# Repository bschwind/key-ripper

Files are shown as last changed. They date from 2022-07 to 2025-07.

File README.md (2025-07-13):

# key-ripper

A keyboard personalized for myself, designed in KiCad, with custom firmware written in Rust.

key-ripper
feet
macbook-keyboard
usb-c

The story behind this board can be found in [this reddit post](https://www.reddit.com/r/MechanicalKeyboards/comments/vtlujd/i_built_a_keyboard_pcb_and_wrote_firmware_for_it/).

I also gave a (time-constrained) talk on making this keyboard which you can view [here](https://www.youtube.com/watch?v=x7LQevYn7d0).
Sadly I didn't get to cover everything I wanted to talk about when it comes to embedded Rust, but I hope you find it entertaining.

## Main Features and Requirements

* Be cheap to manufacture (can easily be ordered and fabricated by JLCPCB, uses an RP2040)
* USB C Connector
* Have dedicated function keys
* Reduce friction changing between a macbook keyboard and this one
* Stay relatively compact
* Full sized arrow keys with a gap (on the left and right) for easily finding the up arrow without looking
* No right shift key (this allows for the arrow keys to sit below the Enter key, and I never use right shift)
* Support for screw-in stabilizers first and foremost, along with snap-in stabilizers, and plate-mounted stabilizers when using a top plate
* Can sit on top of a macbook keyboard
* Easy to assemble - order a PCB, press it into the 3D printed case, and use 4 optional screws if the fit isn't snug
* Firmware written in Rust, debuggable with knurling-rs

## Setup

* Order a PCB with the production files from the [latest release](https://github.com/bschwind/key-ripper/releases).
* When you receive the board, plug it in via USB C and follow [the instruction to flash the firmware](https://github.com/bschwind/key-ripper/blob/main/firmware/README.md).

## 3D Printed Case

The STEP files for the case are available in the [case directory](./case).

They were produced with Rust bindings to OpenCascade. You can find the code for the keyboard case [here](https://github.com/bschwind/opencascade-rs/blob/2eefc2c0322c1cb65bd3279fbedeba416aef8858/examples/src/keyboard_case.rs).

The case can be printed as two separate parts with a dovetail connection (use your slicer and cut up the parts for whatever suits your print bed size), or it can be printed as one full piece.

The PCB can then be slotted into the case with the top edge first (the edge with the USB connector), then press the bottom edge in to fit it into the case. It's usually a snug fit. You can then use 4 M2x4 flat head "laptop screws" to secure the PCB in the middle two holes on the top and bottom edges.

The case feet can be printed and pressed directly into the bottom of the case. The STEP files were printed on a Prusa MK4 and MK3S, both of which had successful tolerances for the press-fit of the case feet.

## Current Version (v0.3.1)

[v0.3.1 PCBWay Production Files](https://github.com/bschwind/key-ripper/releases/tag/v0.3.1)

Version v0.3.1 adds an ESD protector on the USB connector, and was kindly sponsored and manufactured by PCBWay.

pcbway-matte-black-rp2040

pcbway-matte-black-usb-c

## v0.3

[v0.3 JLCPCB Production Files](https://github.com/bschwind/key-ripper/releases/tag/v0.3)

Version 0.3 adds some iterative hardware improvements over v0.2:

* Added support for threaded inserts on the PCB
* Added pass-through holes for M2 hex spacers
* Better impedance matching on the USB lines
* Added a cross-hatch copper pour to reduce warping compared to a solid copper pour
* Added some test points on the board
* Moved many components to a 1608 metric size for easier soldering
* Added an optional TRRS connector footprint for connecting to a debug probe
* Switched to a much smaller QSPI flash chip
* Added fancier patterns on the top and bottom plates

## v0.2

[v0.2 JLCPCB Production Files](https://github.com/bschwind/key-ripper/releases/tag/v0.2)

Version 0.2 improves upon some of the issues in v0.1, with some intentional choices that could be seen as a downgrade:

* Added a copper pour on both sides for a flatter PCB
* Shifted a few components away from the screw-in stabilizer holes to avoid screw washers touching the components
* Fixed some silkscreens for the reset and USB boot buttons
* Fixed the alignment of the F5 key
* **Controversial** - Changed the switch footprint to normal MX soldered switches instead of Kailh hotswap footprints. This allows for simpler boards that don't require a top plate.

## Version v0.1

Version 0.1 _works_ but there are some issues:

* The PCB warps during SMT reflow because there is a copper pour on only one side
* The silkscreens are not labeled well (SW1, SW2, SW3, etc. instead of Q, W, E, R, etc.)
* The F5 key is slightly more to the left of the F6 key than it should be, which leads to incompatible top plates between v0.1 and v0.2

Version 0.1 uses Kailh hotswap sockets. Combined with the top plate, this is good for trying out different switches, but adds complexity
in the build process. It requires more parts, and I had to 3D print 3.4mm M2 spacers.

[v0.1 JLCPCB Production Files](https://github.com/bschwind/key-ripper/releases/tag/v0.1)

PCB Front
PCB Back

## Production Files

For every PCB fabrication order, I make a github release and upload the files I used to make the order.

You can see a list of releases [here](https://github.com/bschwind/key-ripper/releases).

## Create a Gerber File

For most PCB fabrication shops, they expect gerber files, which are essentially files that describe the layout of pads/traces/geometry for each layer in a PCB. They also contain the drill locations if your PCB has any holes. All these layers should be placed in a directory and compressed to a zip file for uploading.

To create a gerber zip in KiCAD:

* Open up PCBNEW (KiCAD's PCB design tool)
* Select `File` -> `Plot`
* Select the following layers:
    * F.Cu
    * B.Cu
    * F.Paste
    * B.Paste
    * F.SilkS
    * B.SilkS
    * F.Mask
    * B.Mask
    * Edge.Cuts
* Leave all the other settings to their defaults
* Output to a directory named `gerber` (this is just convention, any name will do)
* Click `Plot`
* Next click `Generate Drill Files` with an `Excellon` drill file format, and a `Gerber` map file format
* Make sure the `Drill Units` are in `Millimeters`
* Output to the same directory you did for the previous gerber layers
* Click `Generate Drill File`
* Zip the `gerber` directory into a `gerber.zip` file and it's ready to upload!

**Note**: Check the PCB vendor's website for special KiCAD instructions, as they sometimes prefer certain settings when exporting.

OSHPark can directly accept `*.kicad_pcb` files so you don't need to export gerbers when ordering there.

## Create a Bill of Materials (for JLCPCB)

From the schematic viewer:

* Click the "BOM" button in the upper right toolbar
* Use the `bom_csv_grouped_by_value_with_fp`
* The output file won't have a `.csv` extension, so add it

Modify the CSV file:
* Rename the following columns:
    * `Ref` -> `Designator`
    * `Qnty` -> `Quantity`
* Delete the following columns:
    * `Cmp name`
    * `Description`
    * `Vendor`
* Add the following column:
    * `LCSC Part #`
* Remove any part rows you don't need to populate
* For each part, look it up on `jlcpcb.com/parts` and copy over both the footprint and the LCSC part number into their respective columns

In general, try to use as many "basic parts" as you can from JLCPCB. Each "extended part" costs an extra 300 yen per board.

## Create the Position File (for JCLPCB's pick-and-place machines)

From KiCad's PCB design tool:

* `File` -> `Fabrication Outputs` -> `Footprint Position (.pos) File`
* `Format`: `CSV`
* `Units`: `Millimeters`
* `Files`: `Single file for board`
* `Include footprints with SMD pads even if not marked Surface Mount`: `checked`
* Click `Generate Position File`

Modify the CSV file:

* Rename the following columns:
    * `Ref` -> `Designator`
    * `Qnty` -> `Quantity`
    * `Val` -> `Value`
    * `PosX` -> `Mid X`
    * `PosY` -> `Mid Y`
    * `Rot` -> `Rotation`
    * `Side` -> `Layer`

When uploading to JLCPCB, you may need to modify the rotation values. It will show you red dots on pin 1 for the relevant components, as well as a red `+` for components with polarity, so double check against your silkscreen and placement. Positive rotation goes counter-clockwise, so if you need to rotate a part counter-clockwise one turn, add 90 degrees. Subtract 90 to rotate one turn clockwise, and modulo 360 degrees to keep the overall rotation value positive.

## Firmware Debugging

Set the `DEFMT_LOG` environment variable.

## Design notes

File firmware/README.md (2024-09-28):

# key-ripper

## Dependencies

* [Rust Toolchain](https://rustup.rs/)

```
rustup target add thumbv6m-none-eabi
cargo install elf2uf2-rs
```

## Flash Code

If you just got the PCB from a PCB manufacturer, chances are you can plug in the board directly via USB C and it will show up as a USB mass-storage device, ready for flashing.

If not, hold the "USB Boot" button (near the QSPI chip), and either press the reset button or re-insert the USB cable to put the board in USB mass-storage bootloader mode.

```
cargo run --release
```

### Troubleshooting

If you get an error such as:

```
Error: "Memory segment 0x010000->0x010094 is outside of valid address range for device"
```

Double check that your `RUSTFLAGS` environment variable, as it will take precedence over the values set in `./cargo/config.toml`.

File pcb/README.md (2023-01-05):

# Notes

* The RP2040 samples the QSPI_SS line on boot. If this line is low, it will boot into its USB bootloader mode (i.e. enumerate as a mass storage device so you can upload new firmware). If this line is high on boot, it will start reading program instructions from the quad-SPI flash chip.

## Layout Notes

Just some measurements I've written down for my own designs are:
standard MX cutout - 14×14mm
distance between switches (center to center) - 19.05mm (both vertically and horizontally)
distance between caps - 0.95mm
distance between cap and case side - 0.475mm

Calculation example (60% case):
width of a case: 6 + (19.05 * 15) + (0.475 * 2) = 3mm bezel on each side, gap between case side and caps on each side, 15 keys in row.

Edit: 19.05mm distance between switches are only correct if they are two 1u keys. So for something like a 1.5u and 1u key distance between their centers would be (19.05 * 1.5)mm.

## TRRS Debug Connector

The footprint for the debug connector is a 3.5mm TRRS jack (part number PJ-320A, LCSC part number C2884926).

This footprint should be equivalent to the MJ-4PP-9 connector which is more easily found in Japan.

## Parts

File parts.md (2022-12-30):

# Parts List

Use 0402 metric (1005 imperial) footprints for all capacitors and resistors where possible.

## JLCPCB Parts

1x RP2040
    Extended
    C2040
    https://datasheet.lcsc.com/lcsc/2201101600_Raspberry-Pi-RP2040_C2040.pdf

1x USB C Connector
    Extended
    C165948
    https://datasheet.lcsc.com/lcsc/2205251630_Korean-Hroparts-Elec-TYPE-C-31-M-12_C165948.pdf

1x 3.3V Voltage Regulator
    Basic
    XC6206P
    C5446
    https://datasheet.lcsc.com/szlcsc/Torex-Semicon-XC6206P332MR_C5446.pdf

1x Schottky Diode
    Basic
    5819W SOD-123
    C8598
    https://datasheet.lcsc.com/szlcsc/Changjiang-Electronics-Tech-CJ-B5819W_C8598.pdf

1x Ferrite Bead
    Basic
    Sunlord GZ2012D101TF
    C1015
    https://datasheet.lcsc.com/szlcsc/Sunlord-GZ2012D101TF_C1015.pdf

1x Resettable Fuse
    Extended
    TLC-PSMD050
    C261942
    https://datasheet.lcsc.com/szlcsc/TLC-Electronic-TLC-PSMD050_C261942.pdf

1x Green LED
    Basic
    0805 Light Emitting Diodes (LED) ROHS
    C2297

1x Crystal Resonator (12MHz, 20pF load)
    Basic
    X322512MSB4SI
    C9002
    https://datasheet.lcsc.com/lcsc/2103291203_Yangxing-Tech-X322512MSB4SI_C9002.pdf

1x 16MB QSPI Flash
    Basic
    W25Q128JVSIQ
    C97521
    https://datasheet.lcsc.com/lcsc/1811142111_Winbond-Elec-W25Q128JVSIQ_C97521.pdf

Nx Kailh Hotswap Sockets
    Extended
    CPG151101S11
    C2803348
    https://jlcpcb.com/parts/componentSearch?isSearch=true&searchTxt=CPG151101S11

Nx Diodes
    Basic
    1N4148W
    C81598
    SOD-123
    https://datasheet.lcsc.com/lcsc/1811061725_ST-Semtech-1N4148W_C81598.pdf

2x tactile switch
    Basic
    TS-1187A-B-A-B
    C318884
    https://datasheet.lcsc.com/lcsc/2002271431_XKB-Connectivity-TS-1187A-B-A-B_C318884.pdf

1 uF C
    Basic
    0402 footprint
    50V 1uF X7R ±10% 0805  Multilayer Ceramic Capacitors MLCC - SMD/SMT ROHS
    C52923

0.1uF (100nF) C
    Basic
    50V 100nF X7R ±10% 0402  Multilayer Ceramic Capacitors MLCC - SMD/SMT ROHS
    C307331

30 pF C
    Basic
    50V 30pF C0G ±5% 0402  Multilayer Ceramic Capacitors MLCC - SMD/SMT ROHS
    C1570

27 ohm R
    Basic
    1/10W Thick Film Resistors 75V ±1% ±200ppm/℃ -55℃~+155℃ 27Ω 0603  Chip Resistor - Surface Mount ROHS
    C25190

1k ohm R
    Basic
    1/16W Thick Film Resistors 50V ±1% ±100ppm/℃ -55℃~+155℃ 5.1kΩ 0402  Chip Resistor - Surface Mount ROHS
    C11702

10k ohm R
    Basic
    1/16W Thick Film Resistors 50V ±1% ±100ppm/℃ -55℃~+155℃ 10kΩ 0402  Chip Resistor - Surface Mount ROHS
    C25744

5.1k ohm R
    Basic
    1/16W Thick Film Resistors 50V ±1% ±100ppm/℃ -55℃~+155℃ 5.1kΩ 0402  Chip Resistor - Surface Mount ROHS
    C25905

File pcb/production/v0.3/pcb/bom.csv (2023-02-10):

Comment | Designator | Footprint | LCSC
2.2uF | C1,C2,C19 | 0603 | C23630
100nF | C3,C8,C9,C10,C11,C12,C13,C14,C15,C16,C17,C18 | 0402 | C307331
1uF | C4,C5 | 0402 | C52923
30pF | C6,C7 | 0603 | C1658
D_Small | D1,D2,D3,D4,D5,D6,D7,D8,D9,D10,D11,D12,D13,D14,D15,D16,D17,D18,D19,D20,D21,D22,D23,D24,D25,D26,D27,D28,D29,D30,D31,D32,D33,D34,D35,D36,D37,D38,D39,D40,D41,D42,D43,D44,D45,D46,D47,D48,D49,D50,D51,D52,D53,D54,D55,D56,D57,D58,D59,D60,D61,D62,D63,D64,D65,D66,D67,D68,D69,D70,D71,D72,D73,D74,D75 | SOD-123 | C81598
5819W | D76,D78 | SOD-123 | C8598
Power LED (Green) | D77 | 0805 | C2297
TLC_PSMD050 | F1 | 0805 | C261942
100@100MHz | FB1 | 0805 | C1015
27 ohm | R1,R2 | 0603 | C25190
1k ohm | R3,R5,R9 | 0603 | C21190
10k ohm | R4,R8 | 0603 | C25804
5.1k | R6,R7 | 0603 | C23186
RP2040 | U1 | LQFN-56_EP_7.0x7.0x0.4P | C2040
TYPE-C-31-M-12 | U2 | TYPE-C-31_L8.94_W7.3 | C165948
XC6206PxxxMR | U3 | SOT-23-3L | C5446
W25Q16JVUXIQ | U4 | USON-8-EP(2x3) | C2843335
USB Boot | U5 | SMD-SW-4_5.1x5.1x1.5 | C318884
Reset | U6 | SMD-SW-4_5.1x5.1x1.5 | C318884
12MHz - 20pF | Y1 | SMD3225-4P | C9002

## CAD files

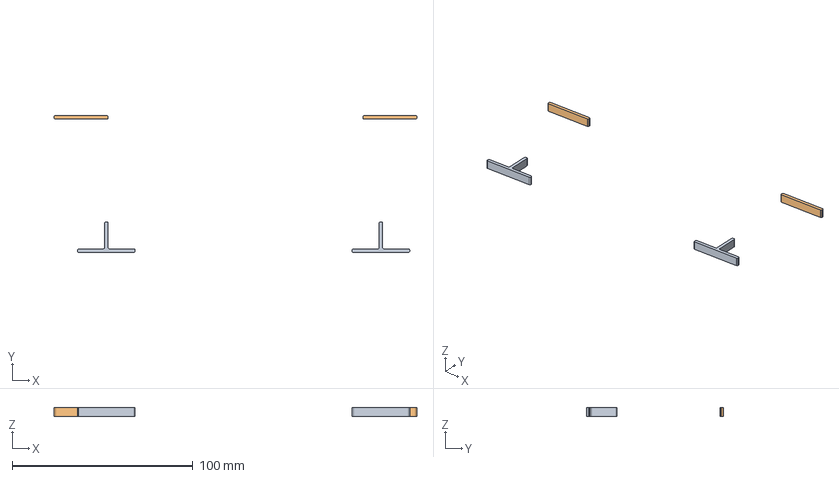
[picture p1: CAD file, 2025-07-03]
case/case_feet.step
201.1 x 75.8 x 5.00 mm

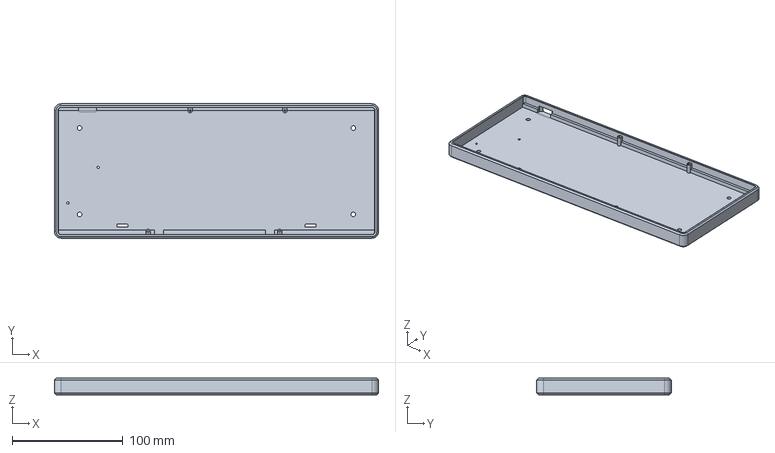
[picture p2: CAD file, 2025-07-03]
case/keyboard.step
293.1 x 121.7 x 15.1 mm

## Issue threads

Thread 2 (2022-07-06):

Add a ground pour to both sides

bschwind, 2022-07-06:
The PCB gets warped excessively during SMT reflow when the amount of copper on each side is unbalanced.

bschwind, 2022-07-10:
Fixed by d41e0e987a201cc1591b78f466c40796db80041b

Closed 2022-07-10.

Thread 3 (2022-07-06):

Fix silkscreen labels

bschwind, 2022-07-06:
At some point, the silkscreen labels for the keys and the push buttons got "reset" to their default kicad part labels (e.g. "SW1" or "U6").

bschwind, 2022-07-26:
Fixed by 72a85561d25322354060a1e48d76111535a5a0b2

The switch footprint square has been removed and the `SW**` number indicators have been moved under the switch.

Closed 2022-07-26.

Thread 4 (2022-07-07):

Screw-in stabilizer washers partially overlap some components

bschwind, 2022-07-07:
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

bschwind, 2022-07-10:
Fixed by 4a27d429b65c34ad5d87b87f041a81868366f658

Closed 2022-07-10.

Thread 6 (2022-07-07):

F5 key is spaced too far left of the F6 key

bschwind, 2022-07-07:
This was just a mistake in the PCB layout, oops!

bschwind, 2022-07-10:
Fixed by 811e14eb88a7b8bd4877243777f387e24d2578af

Closed 2022-07-10.

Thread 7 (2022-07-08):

Replace hard-wired power LED with a firmware-controlled LED

bschwind, 2022-07-08:
It's good to know power is working, but a firmware controlled LED can help with debugging and can be turned off when not in use. The current power LED is quite bright.

bschwind, 2022-07-10:
Fixed by 8c3728c21a9c1a877c4a96404b246dc875074b08

Closed 2022-07-10.

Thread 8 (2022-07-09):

Startup takes awhile when plugged in to a computer

bschwind, 2022-07-09:
It sometimes takes up to 10 seconds for the board to start acting as a keyboard after being plugged into a computer.

Not sure if I have some issues with the boot circuitry, which causes some ROM bootloader to timeout and then switch to QSPI booting, or if it's a software issue. Will need further debugging.

bschwind, 2022-07-09:
Increasing the `scan_countdown` timer to a longer value (in my case, I tried 80ms) seems to allow the keyboard to respond much faster when plugged in.

Closed 2022-07-09.

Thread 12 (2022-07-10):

Replace kailh hotswap socket footprint with standard MX footprint

bschwind, 2022-07-10:
The kailh hotswap sockets are kind of a pain, take up extra board space, and are incompatible with a design where you might want to solder the switches instead of plugging them in.

Instead, a standard MX footprint should be used, and then MillMax 3305-X sockets can be installed:

https://www.mill-max.com/products/new/receptacles-make-keyswitch-hot-swapping-effortless

bschwind, 2022-07-10:
Fixed by dcfef5a7472da8d3b487b35a76284e92f32b188c

Closed 2022-07-10.

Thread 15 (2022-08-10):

Automate more kicad operations

bschwind, 2022-08-10:
See the comment [here](https://news.ycombinator.com/item?id=31236936)

Copy-pasted for posterity:

```
I gathered my setup from a few sources but the main one is https://github.com/INTI-CMNB/kicad_auto and https://github.com/INTI-CMNB/KiBot . Here is my current setup for gitlab:
When adding components, add "LCSC" to overall schematic (BOM export will fail if added to each part separately (join issue)) and the part number in each part in order to use the JLCPCB assembly service. Only parts with LCSC column are exported in the JLCPCB BOMs.

.gitlab-ci.yml

  ...
  tests:
    image: setsoft/kicad_auto:dev_k6
    stage: testing
    script:
      - "[ -f *.kicad_pcb ] && kibot -c test.kibot.yaml"
    tags:
      - docker

  pcb_outputs:
    image: setsoft/kicad_auto:dev_k6
    stage: gen_fab
    script:
      - "[ -f *.kicad_pcb ] && kibot -c output.kibot.yaml"
    only:
      refs:
      - master
    artifacts:
      when: always
      paths:
        - Fabrication/
    tags:
      - docker
  ...
test.kibot.yaml
  kibot:
    version: 1

  preflight:
    run_erc: false
    update_xml: false
    run_drc: true
    check_zone_fills: true
    ignore_unconnected: false
output.kibot.yaml
  # Gerber and drill files for JLCPCB, without stencil
  # URL: https://jlcpcb.com/
  kibot:
    version: 1

  filters:
    - name: only_jlc_parts
      comment: 'Only parts with JLC (LCSC) code'
      type: generic
      include_only:
        - column: 'LCSC'
          regex: '^C\d+'

  variants:
    - name: rotated
      comment: 'Just a place holder for the rotation filter'
      type: kibom
      variant: rotated
      pre_transform: _rot_footprint

  outputs:
    - name: JLCPCB_gerbers
      comment: Gerbers compatible with JLCPCB
      type: gerber
      dir: JLCPCB
      options: &gerber_options
        exclude_edge_layer: true
        exclude_pads_from_silkscreen: true
        plot_sheet_reference: false
        plot_footprint_refs: true
        plot_footprint_values: false
        force_plot_invisible_refs_vals: false
        tent_vias: true
        use_protel_extensions: true
        create_gerber_job_file: false
        disable_aperture_macros: true
        gerber_precision: 4.6
        use_gerber_x2_attributes: false
        use_gerber_net_attributes: false
        line_width: 0.1
        subtract_mask_from_silk: true
      layers:
        # Note: a more generic approach is to use 'copper' but then the filenames
        # are slightly different.
        - F.Cu
        - B.Cu
        - F.Paste
        - B.Paste
        - F.SilkS
        - B.SilkS
        - F.Mask
        - B.Mask
        - Edge.Cuts

    - name: JLCPCB_drill
      comment: Drill files compatible with JLCPCB
      type: excellon
      dir: JLCPCB
      options:
        pth_and_npth_single_file: false
        pth_id: '-PTH'
        npth_id: '-NPTH'
        metric_units: false
        output: "%f%i.%x"

    - name: JLCPCB
      comment: ZIP file for JLCPCB
      type: compress
      dir: Fabrication/JLCPCB
      options:
        files:
          - from_output: JLCPCB_gerbers
            dest: /
          - from_output: JLCPCB_drill
            dest: /

    - name: ibom
      comment: Interactive BOM
      type: ibom
      dir: Fabrication/ibom
      options:
        dark_mode: true

    - name: 'JLCPCB_position'
      comment: "Pick and place file, JLCPCB style"
      type: position
      dir: Fabrication/JLCPCB-BOM
      options:
        variant: rotated
        output: '%f_cpl_jlc.%x'
        format: CSV
        units: millimeters
        separate_files_for_front_and_back: false
        only_smd: true
        columns:
          - id: Ref
            name: Designator
          - Val
          - Package
          - id: PosX
            name: "Mid X"
          - id: PosY
            name: "Mid Y"
          - id: Rot
            name: Rotation
          - id: Side
            name: Layer

    - name: 'JLCPCB_bom'
      comment: "BoM for JLCPCB"
      type: bom
      dir: Fabrication/JLCPCB-BOM
      options:
        output: '%f_%i_jlc.%x'
        exclude_filter: 'only_jlc_parts'
        ref_separator: ','
        columns:
          - field: Value
            name: Comment
          - field: References
            name: Designator
          - Footprint
          - field: 'LCSC'
            name: 'LCSC part number'
        csv:
          hide_pcb_info: true
          hide_stats_info: true
          quote_all: true*
```

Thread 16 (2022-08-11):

Allow a key combo on startup for going into bootloader mode

bschwind, 2022-08-11:
Once I make a case for this board, it will be hard to access the USB boot button, which needs to be pressed when the RP2040 is powered up to be able to flash new firmware to it.

The firmware should allow for holding some key or key combination on power up to put it into bootloader mode.

Closed 2022-08-11.

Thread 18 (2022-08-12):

Use hatched copper pours for (hopefully) less PCB warping

bschwind, 2022-08-12:
v0.2 improved on v0.1 by having more balanced copper pours on both layers, but it is still _slightly_ warped.

I'm not 100% sure, but perhaps a hatched copper pour would reduce warping even more.

bschwind, 2023-02-06:
Current favorite parameters:

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

bschwind, 2023-02-06:
Implemented by 6a3291f3f06b6b3bd6cb34058a419782e399f28b

Closed 2023-02-06.

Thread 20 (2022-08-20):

Fix EMC issues, and possibly warping as a side-effect

aw, 2022-08-20:
Hi Brian, perhaps I can suggest switching to a 4-layer PCB and make the copper pours on the inner layers (GND/+3.3V), and keep the traces on the top/bottom layers.

You might have a high noise/EMI problem:

1. There are many slots in the ground planes which create "islands" and cause problems for the current return path (where would the return current flow?).
2. The signals on the bottom layer cross the slots in the top layer (and vice-versa), which is basically creating multiple dipole antennas which will radiate. See below: the red trace (F.cu) goes right through an opening (slot) in the ground plane (B.cu), and the green trace (B.cu) goes right through an opening (slot) in the other ground plane (F.cu).

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

In those areas where the green and red traces cross, you literally have no ground.. solving this might also fix your warping issues in #18 because you would then end up with nice clean uninterrupted ground/+3.3V planes, and much more balanced copper pours.

(these are just assumptions by the way, forgive me if i'm wrong) 😆

aw, 2022-08-20:
Just to give an idea, here's what it would look like with the ground pour in a middle layer (4-layer), with signals on top and bottom:

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

Notice the lack of slots and thermal relief around the SMD components?

aw, 2022-08-20:
And finally, with the +3.3V pour in the other middle layer, you can now eliminate all these long +3.3V traces (highlighted below) and simply drop some nearby vias to connect to that layer:

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

bschwind, 2022-08-20:
Hey @aw thanks for reporting in!

This was one of the first decisions I struggled with, until I looked at JLCPCB quotes.

For a board this size, 4 layers is significantly more expensive than a 2 layer board:

4 Layer
* 285.7mm x 116.7mm, 4 Layer, 1.6 thickness, black soldermask, lead-free HASL, 1 oz copper: 10137 yen + shipping

2 Layer
* 285.7mm x 116.7mm, 2 Layer, 1.6 thickness, black soldermask, lead-free HASL, 1 oz copper: 2632 yen + shipping

I also get an extra slight penalty for my choice of black soldermask and lead-free HASL for the 4 layer board:
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

One of the goals is to be able to produce this cheaply, so I opted to try to fit things in 2 layers to see if it's feasible. Of course 4 layers would be much easier to route, but I also feel like my routing skills improved after this project a bit :)

I won't try to claim EMI/noise isn't a problem with this board, as I don't have the equipment to make that claim. I believe the highest speed signal on the board is the USB line, running at most USB Full Speed (12Mbps). I did try to make sure I had an uninterrupted ground plane underneath those data lines, and tried to provide short ground return paths where I had to interrupt it, as shown:

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

For the majority of the rest of the lines in the board, they are used as such:

* One by one, each column on the board is set high via a GPIO pin. The MCU then sleeps a bit to make sure the signal has propagated.
* All GPIO row pins are read, to see which are high, which determines key presses for those rows/columns

In that sense, I'm not worried about the signals interfering with each other, but I understand how an interrupted ground can cause radiation issues. From what I understand, it's related to the rise time of the signal and not the frequency.

So could I possibly attach small valued capacitors or something similar which would reduce the rise time?

Otherwise, the board functions fine, but I unfortunately don't have the equipment to measure EMI (let me know if you do, or know someone who does though!).

Just like code performance, I'd prefer to measure a before and after before applying an optimization which may not make an appreciable difference on the end product.

Regarding PCB warping, that issue is more or less solved with v0.2. It's a tiny bit curved, but when combined with a top plate, or screwed into a case, that curve will go away. I could experiment with a hatched ground pour instead of a solid one to see if that improves it further.

aw, 2022-08-20:
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

Haha yeah I think that's a pretty big price difference. From an electrical standpoint if you've already confirmed it "works fine" and doesn't have any issues then great. That's what prototypes are for anyways!

I also don't have EMI test equipment but maybe I should? hmmmm...

bschwind, 2022-08-20:
I've been using it as my main keyboard for a month or so now, it works well! There are some usb descriptor issues I need to sort out on macos but otherwise it's stable and totally usable!

Can't claim no EMI noise though, as I said. I'd be super curious to test it out.

Closed 2022-08-27.

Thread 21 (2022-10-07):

Keyboard sometimes not recognized when plugged in

bschwind, 2022-10-07:
I'm not yet sure if this is a USB timing issue, a HID descriptor issue, or something else. It can be reproduced fairly easily by plugging in the keyboard to a machine and trying to type. Sometimes it isn't recognized as a keyboard for tens of seconds, and pressing the firmware Reset button will often help it get recognized.

bschwind, 2024-06-22:
I noticed removing the LED section from the HID descriptor fixes this issue, maybe we weren't handling those messages correctly.

bschwind, 2025-07-03:
Haven't experienced this in quite awhile, closing.

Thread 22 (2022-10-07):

Add screw-holes on the corners of the bottom PCB for standoffs/feet

mcginty, 2022-10-07:
An example setup I like from my previous keyboard: they have some pads, with an optional "tilt" screwhole spots for a higher raised feet set on the back.

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

Having some screw-in feet that are interchangeable/adjustable would be super lovely.

bschwind, 2022-12-30:
Implemented by 14b9a9be80fa695a1f35e55d81ed551870d70178

Closed 2022-12-30.

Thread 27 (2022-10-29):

Case Construction

bschwind, 2022-10-29:
## Tasks

## PCB
- [x] Move row 0 diodes (top row or F row) below their switches instead of above to keep them off the edge of the PCB
- [x] Move row 0 traces to be below the switch

## Plates
- [x] #47

## Case
- [x] Give some space for PCB-mount stabilizer screws, especially the spacebar on the bottom which is very close to the edge
- [x] Add some tolerance to the case walls, maybe 0.2 to 0.5 mm so the PCB and top plate can slot in more easily
- [x] Have the case support being placed on top of a macbook keyboard

## Summary
I'd like to create a case for this keyboard, with three varieties:

* A bottom-plate case, to protect the electronics on the bottom of the PCB. It will still be open from the sides
* A 3D-printable (and maybe eventually aluminum CNC-able) case
* Just a PCB and top plate, with the ability to attach some sort of screw-in rubber feet instead of requiring sticky pads for the feet

Ideally one PCB design will be able to work for all three case styles.

## Measurements

* Currently the tallest component on the board is the USB-C connector, at 3.26mm, followed by the QSPI flash module at 1.95mm, and the kailh hotswap sockets (if they're used) at 1.85mm.

USB-C Connector
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
Flash Memory
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
Kailh Hotswap Socket
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

## Constraints

* The USB-C connector should still be mounted on the same side as the electronics for easier manufacturing
* The reset and USB-boot buttons should ideally still be accessible in some way (side-mounted buttons? holes in the bottom plate?)
* The design should require as few screws as possible, no nuts, and especially no custom 3D-printed spacers as I've used before.

## Bottom Plate Design

Following on the design of other keyboards (such as the [7spro](https://salicylic-acid3.hatenablog.com/entry/7spro-build-guide)), there will be M2 spacers which go _through_ the main PCB, with screws securing it to the top and bottom plates.

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

I would try to get away with 8mm spacers first if the USB connector isn't as tall as it says in the datasheet, otherwise 9mm spacers will have to do.

The screws should be as flat as possible to stay flush with the top and bottom plate. 3-4mm length should be fine.

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

## 3D Case Design

~~Instead of having a bottom plate, the PCB will rest on the bottom of the case, with a slot cut out for the USB connector.~~ There should be raised edges on the top and bottom edges of the case which the PCB will sit on.

There should be slot cutouts of some sort on the PCB edge to allow it to pass through to the bottom, with equivalent "posts" on the case itself, which will prop up the top plate on its edges and keep it at the right height away from the PCB.

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

These can run along the top and bottom of the PCB, the sides may not be necessary.

The "posts" in the 3D case which support the top plate should have M2-sized holes in them to allow for screws to tap into

### To Be Determined
- [x] The drill radius needed to allow M2 spacers to pass through the PCB. (4.5mm)
- [x] How to provide adjustable angles on the keyboard (#22)
- [x] Are these design compatible with assembling the keyboard in a sane/easy order? For the 3D case version, the switches need to be able to be soldered to the PCB before the PCB is placed in the case.
    - From some testing, it seems easiest to snap in some "anchor" switches in the plate on the corners and middle, then progressively add switches from there. The combined force from the snap-in clips on the switches provides enough tension to keep the top plate separated properly from the PCB.

bschwind, 2022-11-12:
Cleanup tasks:

- [ ] Move row 0 diodes (top row or F row) below their switches instead of above to keep them off the edge of the PCB
- [ ] Move row 0 traces to be below the switch

skywhale, 2022-11-28:
If you are okay with an aluminum back plate, then using rivet nuts ([an example](https://www.monotaro.com/p/0674/4832)) is one easy way to make custom feet attachable.

bschwind, 2022-11-29:
Here's a good video showing how a non-hotswap keyboard is expected to be constructed in a case similar to what I want to build:

https://youtu.be/017aGAJiNJg

bschwind, 2022-11-30:
Some findings from @mcginty for adding threading to the PCB:

https://www.keyelco.com/category.cfm/Spacers-Standoffs/Standoffs-Spacers-Inserts-Surface-Mount/id/1335

https://www.mouser.com/ProductDetail/Keystone-Electronics/24929?qs=Znm5pLBrcAJPd1Bwfdw1vA%3D%3D

These could be soldered directly to the PCB as a solid, no-fuss solution to adding threading points on the PCB.

Very similar to @skywhale 's suggestion of rivet nuts, but without the need of a special tool (besides a soldering iron) for attaching it.

bschwind, 2022-12-04:
Progress with the "PCB with threaded inserts" version of the case:

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

bschwind, 2023-01-27:
More progress!

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

Closed 2025-07-03.

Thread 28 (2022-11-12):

Firmware USB Issues

bschwind, 2022-11-12:
Things still aren't quite right with USB on this keyboard, here I'll try to leave a summary of notes for things I want to look into in more detail:

- [ ] The current `bcdHID` is `0x0110`, but I've seen other commercial keyboards with `bcdHID: 0x0100`
- [ ] This keyboard technically doesn't need an `OUT` endpoint since it doesn't have LEDs for things like caps lock
- [ ] `wMaxPacketSize` is 64 for this keyboard, I've seen another with `wMaxPacketSize: 63`
- [ ] In the keyboard HID descriptor, `REPORT_COUNT` and `REPORT_SIZE` are swapped in position.

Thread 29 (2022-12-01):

Use W25Q16JVUXIQ QSPI chip

bschwind, 2022-12-01:
This is motivated by my suspicion that communication with the QSPI flash is not entirely reliable. On many subsequent resets, some boards will fail to boot into their firmware. It _might_ be an issue with QSPI flash communication when loading the firmware.

Part Number: W25Q16JVUXIQ
LCSC Part Number: C2843335
[Datasheet](https://datasheet.lcsc.com/lcsc/2205122030_Winbond-Elec-W25Q16JVUXIQ_C2843335.pdf)

Pros

* Smaller footprint
* Can be placed closer to the RP2040 (better reliability?)
* Still feasible to hand solder if necessary

Cons

* Slightly more expensive
* Harder to solder

bschwind, 2023-01-08:
Done with 95c6bac4b42042a3d10910e42aa0b767082715f7

Closed 2023-01-08.

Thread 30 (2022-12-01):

Use larger passives where space isn't an issue

bschwind, 2022-12-01:
When I was hand soldering this board, some passives were wayyy smaller than necessary. Larger sizes should be used where space isn't an issue.

bschwind, 2023-01-02:
Fixed with bf71a19349987ac357deccb69c8306bc20f59892 and d522288d2d880606d3754e8809d97bedbc7955e7

Closed 2023-01-02.

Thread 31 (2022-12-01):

Consolidate similar valued passives

bschwind, 2022-12-01:
This is just to reduce the overall Bill of Materials size - some resistors and capacitors can probably be grouped into similar values so I don't have tons of unique, one-off values on the board.

bschwind, 2022-12-30:
Closed with 111bc85b8644eafd4140129bed867dc32f94b002

Closed 2022-12-30.

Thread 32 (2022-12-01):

Use teardop pads on vias

bschwind, 2022-12-01:
Especially for the keyswitch solder pads, having teardrops will make the connection to the pad more robust.

Use this [plugin](https://github.com/NilujePerchut/kicad_scripts) to add them.

bschwind, 2023-01-07:
Added by 84a1479ebe5044f023cfedd924f8befa22bb09bf

Closed 2023-01-07.

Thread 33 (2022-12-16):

Add test points on the PCB

bschwind, 2022-12-16:
* VCC
* GND
* Crystal lines
* Reset
* Possibly QSPI lines

bschwind, 2023-01-01:
Done in 348078bce0a6c27c44067b52238403491f565bb3

Closed 2023-01-01.

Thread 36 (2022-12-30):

Adjust USB line thickness to hit target impedance

bschwind, 2022-12-30:
I believe the USB lines need a 90 ohm impedance, so the lines may need to be thicker than they currently are.

bschwind, 2022-12-30:
Fixed by a8aae1a4c21943303b36fa536e8e8bd7fe4289c1

Closed 2022-12-30.

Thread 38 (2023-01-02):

Use a better font for the silkscreen

bschwind, 2023-01-02:

bschwind, 2023-01-07:
Seems this isn't easy in the current version of kicad. Kicad 7 _might_ have support for other system fonts, so I'll leave this out of v0.3.

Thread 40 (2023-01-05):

Make the SWD debug port self-powered

bschwind, 2023-01-05:
Currently the RP2040 is only powered if it has USB power. If you connect a debug probe, you can only inspect it when the peripheral USB cord is already plugged in. This makes debugging harder because every time USB disconnects, you lose your debug session. Considering most of my debugging revolves around USB startup, the debug probe should provide power so the session is uninterrupted.

This will need diodes on the two power sources so voltage doesn't feed back.

bschwind, 2023-01-05:
https://www.reddit.com/r/ErgoMechKeyboards/comments/rt083u/as_a_reminder_while_the_usb_is_plugged_do_not/hqpqktp/

It seems providing power over TRRS is a pretty bad idea, so I'm going to scrap that. Instead, I'll just provide a diode-protected 5V pad that I can optionally solder a wire to if I need to supply power outside of the USB connector.

bschwind, 2023-01-05:
Implemented by b123fd12b0c08b5491edbafc2eb685afea95f521

Closed 2023-01-05.

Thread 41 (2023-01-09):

ESD protection on the USB connector

bschwind, 2023-01-09:
I've heard the part USBLC6-2SC6 is commonly used for ESD protection on the USB data lines.

* SRV05-4 (LCSC part number C85364) - basic part
* ECMF02-4CMX8 (LCSC part number C717678) -extended part
* SMF05CT1G (LCSC part number C15879) - basic part

skywhale, 2024-02-05:
It happened with `lite-matsukazeso` today. When Alisaun touched the volume dial, the panel controller became non-responsive and it triggered a software restart.

```
Feb 05 10:32:27 lite-matsukazeso-portal tonari[888668]: got a serial message: DialValue { diff: 1 }
Feb 05 10:32:27 lite-matsukazeso-portal tonari[888668]: Handling hardware action DialTurns { ticks: 1 }.
Feb 05 10:32:27 lite-matsukazeso-portal tonari[888668]: resetting the audio volume.
Feb 05 10:32:27 lite-matsukazeso-portal tonari[888668]: Share screen audio volume set to: -18 dB
Feb 05 10:32:27 lite-matsukazeso-portal tonari[888668]: portal state updated: PortalState { mode: Normal(NormalState { share_screen_menu_state: NotShown, share_screen_volume: 11 }), casting_state: CastingState { sending_start: None, receiving_start: Some(Timestamp(1707096691.974275954s)) }, current_peer: 10.42.191.39, debug_overlay: false, local_maintenance_state_preference: Nominal, remote_maintenance_state_preference: Nominal }
Feb 05 10:32:27 lite-matsukazeso-portal tonari[888668]: [main] PanelActor handle error: Operation timed out, shutting down.
Feb 05 10:32:27 lite-matsukazeso-portal tonari[888668]: Thread [PanelActor] shutting down the actor system
Feb 05 10:32:27 lite-matsukazeso-portal tonari[888668]: Thread [PanelActor] setting the system_state value to ShuttingDown
Feb 05 10:32:27 lite-matsukazeso-portal tonari[888668]: [main] system shutting down.
Feb 05 10:32:27 lite-matsukazeso-portal tonari[888668]: [main] calling pre-shutdown callback.
```

bschwind, 2024-07-23:
The part I chose wasn't great in terms of availability. This part should be easier to source:

USBLC6-2SC6

https://jlcpcb.com/partdetail/Stmicroelectronics-USBLC62SC6/C7519

Closed 2024-07-23.

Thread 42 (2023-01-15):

QMK Support

bschwind, 2023-01-15:
Pasting here before I open a PR to the main QMK repo:

`keymap.c`

```c
#include QMK_KEYBOARD_H

const uint16_t PROGMEM keymaps[][MATRIX_ROWS][MATRIX_COLS] = {
    [0] =
        {
            {KC_ESC,  KC_F1,   KC_F2,   KC_F3,   KC_F4,   KC_F5,   KC_NO,   KC_F6,   KC_F7,   KC_F8,   KC_F9,   KC_F10,  KC_F11,  KC_F12},
            {KC_GRV,  KC_1,    KC_2,    KC_3,    KC_4,    KC_5,    KC_6,    KC_7,    KC_8,    KC_9,    KC_0,    KC_MINS, KC_EQL,  KC_BSPC},
            {KC_TAB,  KC_Q,    KC_W,    KC_E,    KC_R,    KC_T,    KC_Y,    KC_U,    KC_I,    KC_O,    KC_P,    KC_LBRC, KC_RBRC, KC_BSLS},
            {KC_LCTL, KC_A,    KC_S,    KC_D,    KC_F,    KC_G,    KC_H,    KC_J,    KC_K,    KC_L,    KC_SCLN, KC_QUOT, KC_ENT, KC_NO},
            {KC_LSFT, KC_NO,   KC_Z,    KC_X,    KC_C,    KC_V,    KC_B,    KC_N,    KC_M,    KC_COMM, KC_DOT,  KC_SLSH, KC_UP, KC_NO},
            {MO(1),   KC_LCTL, KC_LALT, KC_LGUI, KC_NO,   KC_NO,   KC_SPC,  KC_NO,   KC_NO,   KC_NO,   KC_RGUI, KC_LEFT, KC_DOWN, KC_RGHT},
        },
    [1] =
        {
            {KC_ESC,  KC_F1,   KC_F2,   KC_F3,   KC_F4,   KC_F5,   KC_NO,   KC_F6,   KC_MEDIA_PREV_TRACK,   KC_MEDIA_PLAY_PAUSE,   KC_MEDIA_NEXT_TRACK,   KC_KB_MUTE,  KC_KB_VOLUME_DOWN,  KC_KB_VOLUME_UP},
            {KC_GRV,  KC_1,    KC_2,    KC_3,    KC_4,    KC_5,    KC_6,    KC_7,    KC_8,                  KC_9,                  KC_0,                  KC_MINS,     KC_EQL,             KC_BSPC},
            {KC_TAB,  KC_Q,    KC_W,    KC_E,    KC_R,    KC_T,    KC_Y,    KC_U,    KC_I,                  KC_O,                  KC_P,                  KC_LBRC,     KC_RBRC,            KC_BSLS},
            {KC_LCTL, KC_A,    KC_S,    KC_D,    KC_F,    KC_G,    KC_H,    KC_J,    KC_K,                  KC_L,                  KC_SCLN,               KC_QUOT,     KC_ENT,             KC_NO},
            {KC_LSFT, KC_NO,   KC_Z,    KC_X,    KC_C,    KC_V,    KC_B,    KC_N,    KC_M,                  KC_COMM,               KC_DOT,                KC_SLSH,     KC_UP,              KC_NO},
            {KC_NO,   KC_LCTL, KC_LALT, KC_LGUI, KC_NO,   KC_NO,   KC_SPC,  KC_NO,   KC_NO,                 KC_NO,                 KC_RGUI,               KC_LEFT,     KC_DOWN,            KC_RGHT},
        },
};
```

`info.json`

```json
{
    "manufacturer": "Brian Schwind",
    "keyboard_name": "key_ripper",
    "maintainer": "bschwind",
    "bootloader": "rp2040",
    "diode_direction": "COL2ROW",
    "features": {
        "bootmagic": true,
        "command": false,
        "console": false,
        "extrakey": true,
        "mousekey": true,
        "nkro": true
    },
    "matrix_pins": {
        "cols": ["GP29", "GP16", "GP17", "GP18", "GP9", "GP10", "GP19", "GP11", "GP12", "GP13", "GP14", "GP20", "GP22", "GP23"],
        "rows": ["GP26", "GP25", "GP27", "GP28", "GP15", "GP24"]
    },
    "processor": "RP2040",
    "url": "https://github.com/bschwind/key-ripper",
    "usb": {
        "device_version": "0.2.0",
        "pid": "0x0200",
        "vid": "0xFEED"
    },
    "layouts": {
        "LAYOUT": {
            "layout": [
                { "matrix": [0, 0], "x": 0, "y": 0 },
                { "matrix": [0, 1], "x": 1, "y": 0 },
                { "matrix": [0, 2], "x": 2, "y": 0 },
                { "matrix": [0, 3], "x": 3, "y": 0 },
                { "matrix": [0, 4], "x": 4, "y": 0 },
                { "matrix": [0, 5], "x": 5, "y": 0 },
                { "matrix": [0, 6], "x": 6, "y": 0 },
                { "matrix": [0, 7], "x": 7, "y": 0 },
                { "matrix": [0, 8], "x": 8, "y": 0 },
                { "matrix": [0, 9], "x": 9, "y": 0 },
                { "matrix": [0, 10], "x": 10, "y": 0 },
                { "matrix": [0, 11], "x": 11, "y": 0 },
                { "matrix": [0, 12], "x": 12, "y": 0 },
                { "matrix": [0, 13], "x": 13, "y": 0 },

                { "matrix": [1, 0], "x": 0, "y": 1 },
                { "matrix": [1, 1], "x": 1, "y": 1 },
                { "matrix": [1, 2], "x": 2, "y": 1 },
                { "matrix": [1, 3], "x": 3, "y": 1 },
                { "matrix": [1, 4], "x": 4, "y": 1 },
                { "matrix": [1, 5], "x": 5, "y": 1 },
                { "matrix": [1, 6], "x": 6, "y": 1 },
                { "matrix": [1, 7], "x": 7, "y": 1 },
                { "matrix": [1, 8], "x": 8, "y": 1 },
                { "matrix": [1, 9], "x": 9, "y": 1 },
                { "matrix": [1, 10], "x": 10, "y": 1 },
                { "matrix": [1, 11], "x": 11, "y": 1 },
                { "matrix": [1, 12], "x": 12, "y": 1 },
                { "matrix": [1, 13], "x": 13, "y": 1, "w": 2.00 },

                { "matrix": [2, 0], "x": 0, "y": 2, "w": 1.5 },
                { "matrix": [2, 1], "x": 1.5, "y": 2 },
                { "matrix": [2, 2], "x": 2.5, "y": 2 },
                { "matrix": [2, 3], "x": 3.5, "y": 2 },
                { "matrix": [2, 4], "x": 4.5, "y": 2 },
                { "matrix": [2, 5], "x": 5.5, "y": 2 },
                { "matrix": [2, 6], "x": 6.5, "y": 2 },
                { "matrix": [2, 7], "x": 7.5, "y": 2 },
                { "matrix": [2, 8], "x": 8.5, "y": 2 },
                { "matrix": [2, 9], "x": 9.5, "y": 2 },
                { "matrix": [2, 10], "x": 10.5, "y": 2 },
                { "matrix": [2, 11], "x": 11.5, "y": 2 },
                { "matrix": [2, 12], "x": 12.5, "y": 2 },
                { "matrix": [2, 13], "x": 13.5, "y": 2, "w": 1.5 },

                { "matrix": [3, 0], "x": 0, "y": 3, "w": 1.75 },
                { "matrix": [3, 1], "x": 1.75, "y": 3 },
                { "matrix": [3, 2], "x": 2.75, "y": 3 },
                { "matrix": [3, 3], "x": 3.75, "y": 3 },
                { "matrix": [3, 4], "x": 4.75, "y": 3 },
                { "matrix": [3, 5], "x": 5.75, "y": 3 },
                { "matrix": [3, 6], "x": 6.75, "y": 3 },
                { "matrix": [3, 7], "x": 7.75, "y": 3 },
                { "matrix": [3, 8], "x": 8.75, "y": 3 },
                { "matrix": [3, 9], "x": 9.75, "y": 3 },
                { "matrix": [3, 10], "x": 10.75, "y": 3 },
                { "matrix": [3, 11], "x": 11.75, "y": 3 },
                { "matrix": [3, 12], "x": 12.75, "y": 3, "w": 2.25 },

                { "matrix": [4, 0], "x": 0, "y": 4, "w": 2.25 },
                { "matrix": [4, 2], "x": 2.25, "y": 4 },
                { "matrix": [4, 3], "x": 3.25, "y": 4 },
                { "matrix": [4, 4], "x": 4.25, "y": 4 },
                { "matrix": [4, 5], "x": 5.25, "y": 4 },
                { "matrix": [4, 6], "x": 6.25, "y": 4 },
                { "matrix": [4, 7], "x": 7.25, "y": 4 },
                { "matrix": [4, 8], "x": 8.25, "y": 4 },
                { "matrix": [4, 9], "x": 9.25, "y": 4 },
                { "matrix": [4, 10], "x": 10.25, "y": 4 },
                { "matrix": [4, 11], "x": 11.25, "y": 4 },

                { "matrix": [5, 0], "x": 0, "y": 5 },
                { "matrix": [5, 1], "x": 1, "y": 5 },
                { "matrix": [5, 2], "x": 2, "y": 5 },
                { "matrix": [5, 3], "x": 3, "y": 5, "w": 1.25 },
                { "matrix": [5, 4], "x": 4.25, "y": 5, "w": 6.25 },
                { "matrix": [5, 10], "x": 10.5, "y": 5, "w": 1.25 },
                { "matrix": [5, 11], "x": 11.75, "y": 5 },
                { "matrix": [5, 12], "x": 12.75, "y": 5 },
                { "matrix": [5, 13], "x": 13.75, "y": 5 }
            ]
        }
    }
}
```

`rules.mk`

```
# This file intentionally left blank

```

`README.md`

```md
# key_ripper

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

*A short description of the keyboard/project*

* Keyboard Maintainer: [Brian Schwind](https://github.com/bschwind)
* Hardware Supported: *The PCBs, controllers supported*
* Hardware Availability: *Links to where you can find this hardware*

Make example for this keyboard (after setting up your build environment):

    make key_ripper:default

Flashing example for this keyboard:

    make key_ripper:default:flash

See the [build environment setup](https://docs.qmk.fm/#/getting_started_build_tools) and the [make instructions](https://docs.qmk.fm/#/getting_started_make_guide) for more information. Brand new to QMK? Start with our [Complete Newbs Guide](https://docs.qmk.fm/#/newbs).

## Bootloader

Enter the bootloader in 3 ways:

* **Bootmagic reset**: Hold down the Escape key and plug in the keyboard
* **Physical reset button**: Hold down the USB BOOT button on the PCB, and briefly press the RESET button on the PCB.

```

bschwind, 2023-01-15:
QMK PR: https://github.com/qmk/qmk_firmware/pull/19598

bschwind, 2023-11-12:
This was merged into QMK's mainline branch.

Closed 2023-11-12.

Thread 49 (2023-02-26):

Remove support for plate mounted stabilizers

bschwind, 2023-02-26:
I basically don't use plate mounted stabilizers, and although I tried to have a "one size fits all" plate cutout, it doesn't work well for Durock v2 stabilizers, which are regarded as some of the best screw in stabilizers. (Edit - after reading more on reddit, they are apparently _not_ some of the best, but certainly pretty nice)

So to get the best possible fit and performance, the top plate cutout should be changed to accommodate durock stabilizers and other PCB-mount, screw-in stabilizers.

bschwind, 2023-11-12:
Done in https://github.com/bschwind/key-ripper/commit/a955e04e3e7224cf159dbc17892ad0df489ad800

Closed 2023-11-12.

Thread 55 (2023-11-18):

Add case images and design files, if there are any

DeflateAwning, 2023-11-18:
I'm assuming you also had a 3d-printed case or similar? You should post info about it! If not, my mistake!

bschwind, 2023-11-18:
Yes, I did make a case for it! In fact it's still a work in progress which I recently picked up again.

This is quite obscure, but the code for it is currently in this repository:

https://github.com/bschwind/opencascade-rs/blob/keyboard-case-v2/examples/src/keyboard_case.rs

I actually started that project just to be able to define the case in Rust code, but it has turned into its own project which I also want to flesh out.

Here are some previews of it:

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

Once the code in opencascade-rs gets further along and more mature, I'll move the code for the keyboard case into this repo. Currently I often need new features added to opencascade-rs, so I add those alongside development of the keyboard case.

DeflateAwning, 2023-11-19:
Very neat project, very awesome!

I'm sure you know about OpenSCAD, but check out BOSL2 for OpenSCAD. It has a really nice API (e.g., anchor argument for zcyl, etc.), and could potentially be used as a model as least somewhat for the opencascade-rs project!

bschwind, 2023-11-19:
Could you explain anchor arguments a bit more and what you like about the API? I think I kind of understand them.

For positioning right now my library mostly uses workplanes, which you can construct directly on a typical plane like XY, or they can be constructed from the face of an object.

I still need to figure out a good API for attaching objects together with constraints though.

Closed 2025-07-03.

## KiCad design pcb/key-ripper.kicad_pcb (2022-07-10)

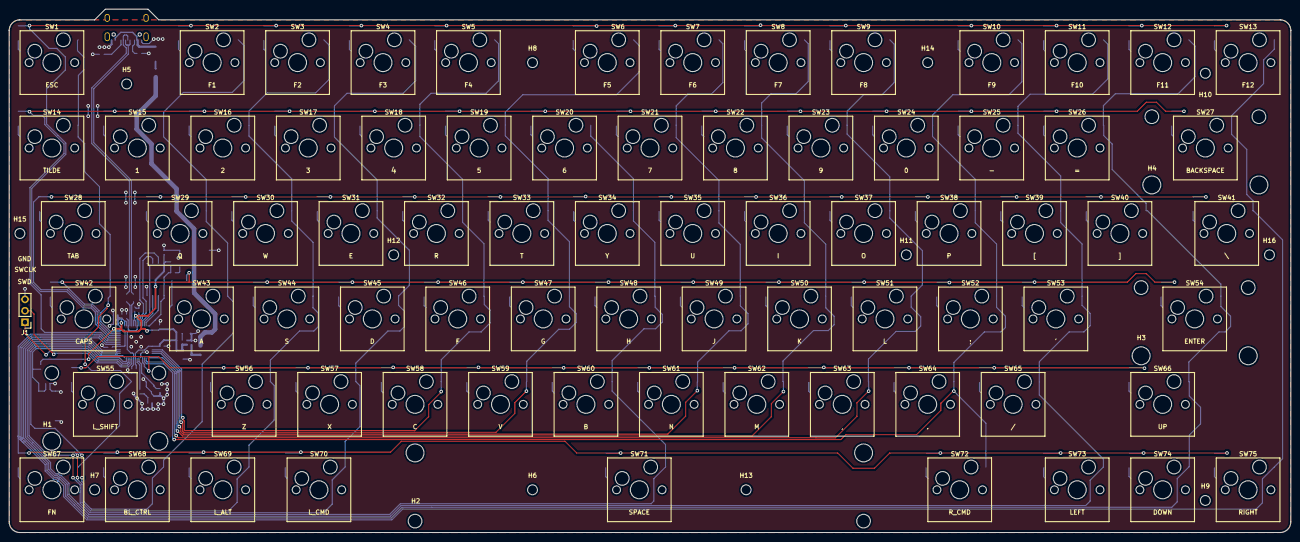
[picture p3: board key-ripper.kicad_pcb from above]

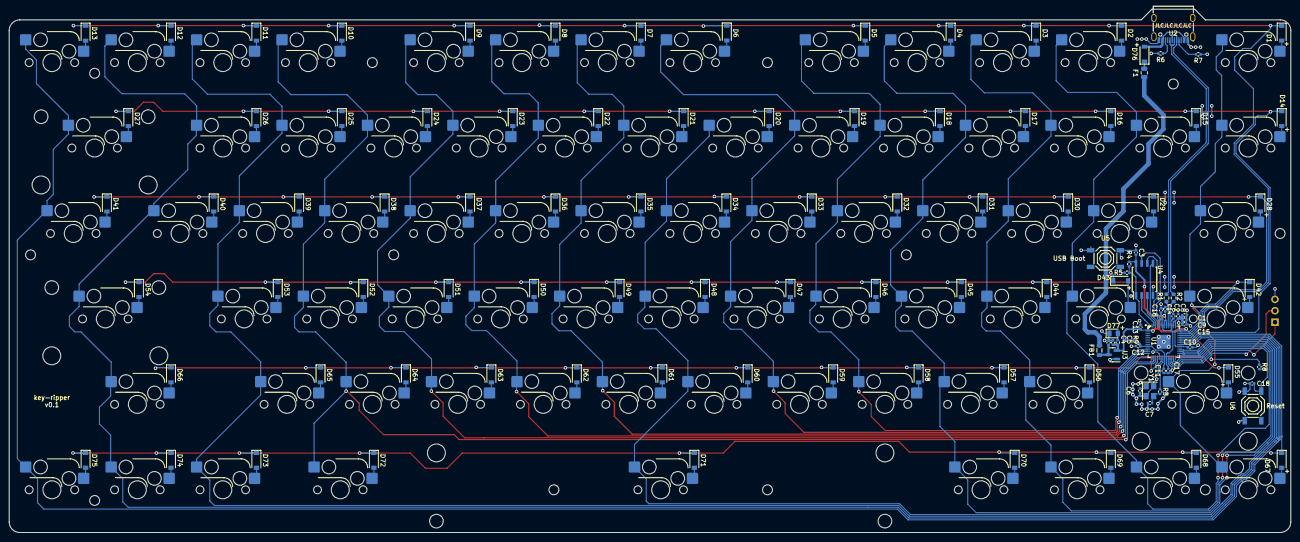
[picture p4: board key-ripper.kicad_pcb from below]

Board: 2 copper layers, 285.8 x 116.7 mm, 205 parts (113 on the bottom side), 122 nets.

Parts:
C1, C2, C4, C5: 1uF; C_0402_1005Metric
C3, C18: 0.1 uF; C_0402_1005Metric
C6, C7: 30pF; C_0402_1005Metric
C8, C9, C10, C11, C12, C13, C14, C15, C16, C17: 100nF; C_0402_1005Metric
D1, D2, D3, D4, D5, D6, D7, D8, D9, D10, D11, D12, D13, D14, D15, D16, D17, D18, D19, D20, D21, D22, D23, D24, D25, D26, D27, D28, D29, D30, D31, D32, D33, D34, D35, D36, D37, D38, D39, D40, D41, D42, D43, D44, D45, D46, D47, D48, D49, D50, D51, D52, D53, D54, D55, D56, D57, D58, D59, D60, D61, D62, D63, D64, D65, D66, D67, D68, D69, D70, D71, D72, D73, D74, D75: D_Small; D_SOD-123
D76: Schottky 5819W; D_SOD-123
D77: Power LED (Green); LED_0805_2012Metric
F1: TLC_PSMD050; Fuse_0805_2012Metric
FB1: 100@100MHz; L_0805_2012Metric
H1: L_SHIFT_STABILIZER; Stabilizer_Cherry_MX_2.00u
H2: SPACE_STABILIZER; Stabilizer_Cherry_MX_6.25u
H3: ENTER_STABILIZER; Stabilizer_Cherry_MX_2.00u
H4: BACKSPACE_STABILIZER; Stabilizer_Cherry_MX_2.00u
H5, H6, H7, H8, H9, H10, H11, H12, H13, H14, H15, H16: M_HOLE; MountingHole_2.2mm_M2
J1: Conn_01x03; PinHeader_1x03_P2.54mm_Vertical
R1, R2: 27 ohm; R_0603_1608Metric
R3, R5: 1k ohm; R_0402_1005Metric
R4, R8: 10k ohm; R_0402_1005Metric
R6, R7: 5.1k; R_0402_1005Metric
R9: 1k5 ohm; R_0402_1005Metric
SW1: ESC; SW_Hotswap_Kailh_MX_1.00u
SW2: F1; SW_Hotswap_Kailh_MX_1.00u
SW3: F2; SW_Hotswap_Kailh_MX_1.00u
SW4: F3; SW_Hotswap_Kailh_MX_1.00u
SW5: F4; SW_Hotswap_Kailh_MX_1.00u
SW6: F5; SW_Hotswap_Kailh_MX_1.00u
SW7: F6; SW_Hotswap_Kailh_MX_1.00u
SW8: F7; SW_Hotswap_Kailh_MX_1.00u
SW9: F8; SW_Hotswap_Kailh_MX_1.00u
SW10: F9; SW_Hotswap_Kailh_MX_1.00u
SW11: F10; SW_Hotswap_Kailh_MX_1.00u
SW12: F11; SW_Hotswap_Kailh_MX_1.00u
SW13: F12; SW_Hotswap_Kailh_MX_1.00u
SW14: TILDE; SW_Hotswap_Kailh_MX_1.00u
SW15: 1; SW_Hotswap_Kailh_MX_1.00u
SW16: 2; SW_Hotswap_Kailh_MX_1.00u
SW17: 3; SW_Hotswap_Kailh_MX_1.00u
SW18: 4; SW_Hotswap_Kailh_MX_1.00u
SW19: 5; SW_Hotswap_Kailh_MX_1.00u
SW20: 6; SW_Hotswap_Kailh_MX_1.00u
SW21: 7; SW_Hotswap_Kailh_MX_1.00u
SW22: 8; SW_Hotswap_Kailh_MX_1.00u
SW23: 9; SW_Hotswap_Kailh_MX_1.00u
SW24: 0; SW_Hotswap_Kailh_MX_1.00u
SW25: -; SW_Hotswap_Kailh_MX_1.00u
SW26: =; SW_Hotswap_Kailh_MX_1.00u
SW27: BACKSPACE; SW_Hotswap_Kailh_MX_2.00u
SW28: TAB; SW_Hotswap_Kailh_MX_1.50u
SW29: Q; SW_Hotswap_Kailh_MX_1.00u
SW30: W; SW_Hotswap_Kailh_MX_1.00u
SW31: E; SW_Hotswap_Kailh_MX_1.00u
SW32: R; SW_Hotswap_Kailh_MX_1.00u
SW33: T; SW_Hotswap_Kailh_MX_1.00u
SW34: Y; SW_Hotswap_Kailh_MX_1.00u
SW35: U; SW_Hotswap_Kailh_MX_1.00u
SW36: I; SW_Hotswap_Kailh_MX_1.00u
SW37: O; SW_Hotswap_Kailh_MX_1.00u
SW38: P; SW_Hotswap_Kailh_MX_1.00u
SW39: [; SW_Hotswap_Kailh_MX_1.00u
SW40: ]; SW_Hotswap_Kailh_MX_1.00u
SW41: \; SW_Hotswap_Kailh_MX_1.50u
SW42: CAPS; SW_Hotswap_Kailh_MX_1.75u
SW43: A; SW_Hotswap_Kailh_MX_1.00u
SW44: S; SW_Hotswap_Kailh_MX_1.00u
SW45: D; SW_Hotswap_Kailh_MX_1.00u
SW46: F; SW_Hotswap_Kailh_MX_1.00u
SW47: G; SW_Hotswap_Kailh_MX_1.00u
SW48: H; SW_Hotswap_Kailh_MX_1.00u
SW49: J; SW_Hotswap_Kailh_MX_1.00u
SW50: K; SW_Hotswap_Kailh_MX_1.00u
SW51: L; SW_Hotswap_Kailh_MX_1.00u
SW52: ;; SW_Hotswap_Kailh_MX_1.00u
SW53: '; SW_Hotswap_Kailh_MX_1.00u
SW54: ENTER; SW_Hotswap_Kailh_MX_2.25u
SW55: L_SHIFT; SW_Hotswap_Kailh_MX_2.25u
SW56: Z; SW_Hotswap_Kailh_MX_1.00u
SW57: X; SW_Hotswap_Kailh_MX_1.00u
SW58: C; SW_Hotswap_Kailh_MX_1.00u
SW59: V; SW_Hotswap_Kailh_MX_1.00u
SW60: B; SW_Hotswap_Kailh_MX_1.00u
SW61: N; SW_Hotswap_Kailh_MX_1.00u
SW62: M; SW_Hotswap_Kailh_MX_1.00u
SW63: ,; SW_Hotswap_Kailh_MX_1.00u
SW64: .; SW_Hotswap_Kailh_MX_1.00u
SW65: /; SW_Hotswap_Kailh_MX_1.00u
SW66: UP; SW_Hotswap_Kailh_MX_1.00u
SW67: FN; SW_Hotswap_Kailh_MX_1.00u
SW68: BL_CTRL; SW_Hotswap_Kailh_MX_1.00u
SW69: L_ALT; SW_Hotswap_Kailh_MX_1.00u
SW70: L_CMD; SW_Hotswap_Kailh_MX_1.25u
SW71: SPACE; SW_Hotswap_Kailh_MX_6.25u
SW72: R_CMD; SW_Hotswap_Kailh_MX_1.25u
SW73: LEFT; SW_Hotswap_Kailh_MX_1.00u
SW74: DOWN; SW_Hotswap_Kailh_MX_1.00u
SW75: RIGHT; SW_Hotswap_Kailh_MX_1.00u
U1: RP2040; rp2040
U2: TYPE-C-31-M-12; simple-usb-c
U3: XC6206PxxxMR; SOT-23
U4: W25Q128JVS; SOIC-8_5.23x5.23mm_P1.27mm
U5: USB Boot; tactile-switch
U6: Reset; tactile-switch
Y1: 12MHz - 20pF; Crystal_SMD_3225-4Pin_3.2x2.5mm

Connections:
+1V1: C2.1, C16.1, C17.1, U1.23 (DVDD), U1.45 (VREG_VOUT), U1.50 (DVDD)
+3V3: C1.1, C3.1, C5.1, C8.1, C9.1, C10.1, C11.1, C12.1, C13.1, C14.1, C15.1, R4.1, R8.2, R9.1, U1.1 (IOVDD), U1.10 (IOVDD), U1.22 (IOVDD), U1.33 (IOVDD), U1.42 (IOVDD), U1.43 (ADC_AVDD), U1.44 (VREG_IN), U1.48 (USB_VDD), U1.49 (IOVDD), U3.2 (VO), U4.8 (VCC)
+5V: C4.1, FB1.2, U3.3 (VI)
CC1: R7.1, U2.A5 (CC1)
CC2: R6.1, U2.B5 (CC2)
CLM0: SW1.2, SW14.2, SW28.2, SW42.2, SW55.2, SW67.2, U1.41 (GPIO29_ADC3)
CLM1: SW2.2, SW15.2, SW29.2, SW43.2, SW68.2, U1.27 (GPIO16)
CLM2: SW3.2, SW16.2, SW30.2, SW44.2, SW56.2, SW69.2, U1.28 (GPIO17)
CLM3: SW4.2, SW17.2, SW31.2, SW45.2, SW57.2, SW70.2, U1.29 (GPIO18)
CLM4: SW5.2, SW18.2, SW32.2, SW46.2, SW58.2, U1.12 (GPIO9)
CLM5: SW6.2, SW19.2, SW33.2, SW47.2, SW59.2, U1.13 (GPIO10)
CLM6: SW20.2, SW34.2, SW48.2, SW60.2, SW71.2, U1.30 (GPIO19)
CLM7: SW7.2, SW21.2, SW35.2, SW49.2, SW61.2, U1.14 (GPIO11)
CLM8: SW8.2, SW22.2, SW36.2, SW50.2, SW62.2, U1.15 (GPIO12)
CLM9: SW9.2, SW23.2, SW37.2, SW51.2, SW63.2, U1.16 (GPIO13)
CLM10: SW10.2, SW24.2, SW38.2, SW52.2, SW64.2, SW72.2, U1.17 (GPIO14)
CLM11: SW11.2, SW25.2, SW39.2, SW53.2, SW65.2, SW73.2, U1.31 (GPIO20)
CLM12: SW12.2, SW26.2, SW40.2, SW54.2, SW66.2, SW74.2, U1.34 (GPIO22)
CLM13: SW13.2, SW27.2, SW41.2, SW75.2, U1.35 (GPIO23)
GND: C1.2, C2.2, C3.2, C4.2, C5.2, C6.2, C7.2, C8.2, C9.2, C10.2, C11.2, C12.2, C13.2, C14.2, C15.2, C16.2, C17.2, C18.2, D77.1 (K), J1.3, R6.2, R7.2, U1.19 (TESTEN), U1.57 (GND), U2.A1 (GND), U2.A12 (GND), U2.B1 (GND), U2.B12 (GND), U3.1 (GND), U4.4 (GND), U5.1 (A), U5.2 (B), U6.1 (A), U6.2 (B), Y1.2, Y1.4
unnamed: D1.2 (A), SW1.1
unnamed: D2.2 (A), SW2.1
unnamed: D3.2 (A), SW3.1
unnamed: D4.2 (A), SW4.1
unnamed: D5.2 (A), SW5.1
unnamed: D6.2 (A), SW6.1
unnamed: D7.2 (A), SW7.1
unnamed: D8.2 (A), SW8.1
unnamed: D9.2 (A), SW9.1
unnamed: D10.2 (A), SW10.1
unnamed: D11.2 (A), SW11.1
unnamed: D12.2 (A), SW12.1
unnamed: D13.2 (A), SW13.1
unnamed: D14.2 (A), SW14.1
unnamed: D15.2 (A), SW15.1
unnamed: D16.2 (A), SW16.1
unnamed: D17.2 (A), SW17.1
unnamed: D18.2 (A), SW18.1
unnamed: D19.2 (A), SW19.1
unnamed: D20.2 (A), SW20.1
unnamed: D21.2 (A), SW21.1
unnamed: D22.2 (A), SW22.1
unnamed: D23.2 (A), SW23.1
unnamed: D24.2 (A), SW24.1
unnamed: D25.2 (A), SW25.1
unnamed: D26.2 (A), SW26.1
unnamed: D27.2 (A), SW27.1
unnamed: D28.2 (A), SW28.1
unnamed: D29.2 (A), SW29.1
unnamed: D30.2 (A), SW30.1
unnamed: D31.2 (A), SW31.1
unnamed: D32.2 (A), SW32.1
unnamed: D33.2 (A), SW33.1
unnamed: D34.2 (A), SW34.1
unnamed: D35.2 (A), SW35.1
unnamed: D36.2 (A), SW36.1
unnamed: D37.2 (A), SW37.1
unnamed: D38.2 (A), SW38.1
unnamed: D39.2 (A), SW39.1
unnamed: D40.2 (A), SW40.1
unnamed: D41.2 (A), SW41.1
unnamed: D42.2 (A), SW42.1
unnamed: D43.2 (A), SW43.1
unnamed: D44.2 (A), SW44.1
unnamed: D45.2 (A), SW45.1
unnamed: D46.2 (A), SW46.1
unnamed: D47.2 (A), SW47.1
unnamed: D48.2 (A), SW48.1
unnamed: D49.2 (A), SW49.1
unnamed: D50.2 (A), SW50.1
unnamed: D51.2 (A), SW51.1
unnamed: D52.2 (A), SW52.1
unnamed: D53.2 (A), SW53.1
unnamed: D54.2 (A), SW54.1
unnamed: D55.2 (A), SW55.1
unnamed: D56.2 (A), SW56.1
unnamed: D57.2 (A), SW57.1
unnamed: D58.2 (A), SW58.1
unnamed: D59.2 (A), SW59.1
unnamed: D60.2 (A), SW60.1
unnamed: D61.2 (A), SW61.1
unnamed: D62.2 (A), SW62.1
unnamed: D63.2 (A), SW63.1
unnamed: D64.2 (A), SW64.1
unnamed: D65.2 (A), SW65.1
unnamed: D66.2 (A), SW66.1
unnamed: D67.2 (A), SW67.1
unnamed: D68.2 (A), SW68.1
unnamed: D69.2 (A), SW69.1
unnamed: D70.2 (A), SW70.1
unnamed: D71.2 (A), SW71.1
unnamed: D72.2 (A), SW72.1
unnamed: D73.2 (A), SW73.1
unnamed: D74.2 (A), SW74.1
unnamed: D75.2 (A), SW75.1
unnamed: D76.1 (K), F1.1
unnamed: D77.2 (A), R9.2
unnamed: F1.2, FB1.1
unnamed: R5.2, U5.3 (C), U5.4 (D)
OSC_IN: C7.1, R3.1, Y1.3
OSC_OUT: C6.1, U1.20 (XIN), Y1.1
QSPI_SCLK: U1.52 (QSPI_SCLK), U4.6 (CLK)
QSPI_SD0: U1.53 (QSPI_SD0), U4.5 (DI(IO0))
QSPI_SD1: U1.55 (QSPI_SD1), U4.2 (DO(IO1))
QSPI_SD2: U1.54 (QSPI_SD2), U4.3 (IO2)
QSPI_SD3: U1.51 (QSPI_SD3), U4.7 (IO3)
QSPI_SS: R4.2, R5.1, U1.56 (QSPI_SS), U4.1 (~CS)
ROW0: D1.1 (K), D2.1 (K), D3.1 (K), D4.1 (K), D5.1 (K), D6.1 (K), D7.1 (K), D8.1 (K), D9.1 (K), D10.1 (K), D11.1 (K), D12.1 (K), D13.1 (K), U1.38 (GPIO26_ADC0)
ROW1: D14.1 (K), D15.1 (K), D16.1 (K), D17.1 (K), D18.1 (K), D19.1 (K), D20.1 (K), D21.1 (K), D22.1 (K), D23.1 (K), D24.1 (K), D25.1 (K), D26.1 (K), D27.1 (K), U1.37 (GPIO25)
ROW2: D28.1 (K), D29.1 (K), D30.1 (K), D31.1 (K), D32.1 (K), D33.1 (K), D34.1 (K), D35.1 (K), D36.1 (K), D37.1 (K), D38.1 (K), D39.1 (K), D40.1 (K), D41.1 (K), U1.39 (GPIO27_ADC1)
ROW3: D42.1 (K), D43.1 (K), D44.1 (K), D45.1 (K), D46.1 (K), D47.1 (K), D48.1 (K), D49.1 (K), D50.1 (K), D51.1 (K), D52.1 (K), D53.1 (K), D54.1 (K), U1.40 (GPIO28_ADC2)
ROW4: D55.1 (K), D56.1 (K), D57.1 (K), D58.1 (K), D59.1 (K), D60.1 (K), D61.1 (K), D62.1 (K), D63.1 (K), D64.1 (K), D65.1 (K), D66.1 (K), U1.18 (GPIO15)
ROW5: D67.1 (K), D68.1 (K), D69.1 (K), D70.1 (K), D71.1 (K), D72.1 (K), D73.1 (K), D74.1 (K), D75.1 (K), U1.36 (GPIO24)
RUN: C18.1, R8.1, U1.26 (RUN), U6.3 (C), U6.4 (D)
SWCLK: J1.2, U1.24 (SWCLK)
SWD: J1.1, U1.25 (SWD)
USB+: R1.2, U2.A6 (DP1), U2.B6 (DP2)
USB-: R2.2, U2.A7 (DN1), U2.B7 (DN2)
USB_MCU+: R1.1, U1.47 (USB_DP)
USB_MCU-: R2.1, U1.46 (USB_DM)
VBUS: D76.2 (A), U2.A4 (VBUS), U2.A9 (VBUS), U2.B4 (VBUS), U2.B9 (VBUS)
XOUT_MCU: R3.2, U1.21 (XOUT)

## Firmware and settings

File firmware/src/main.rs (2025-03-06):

// Simple keyboard firmware. Inspired by the RustyKeys project:
// https://github.com/KOBA789/rusty-keys/blob/main/firmware/keyboard/src/bin/simple.rs

#![no_main]
#![no_std]

mod debounce;
mod hid_class;
mod hid_descriptor;
mod key_codes;
mod key_mapping;
mod key_scan;

use crate::{
    hid_class::HidClass,
    key_scan::{KeyboardReport, TRANSPOSED_NORMAL_LAYER_MAPPING},
};
use core::{
    cell::RefCell,
    convert::Infallible,
    sync::atomic::{AtomicBool, Ordering},
};
use cortex_m::prelude::_embedded_hal_timer_CountDown;
use critical_section::Mutex;
use debounce::Debounce;
use defmt::{error, info, warn};
use defmt_rtt as _;
use embedded_hal::digital::{InputPin, OutputPin};
use fugit::ExtU32;
use key_scan::KeyScan;
use panic_probe as _;
use rp2040_hal::{
    pac::{self, interrupt},
    usb::{self, UsbBus},
    Clock, Watchdog,
};
use usb_device::{bus::UsbBusAllocator, device::UsbDeviceBuilder, prelude::*};

/// The rate of polling of the keyboard itself in firmware.
const SCAN_LOOP_RATE_MS: u32 = 1;
/// The number of milliseconds to wait until a "key-off-then-key-on" in quick succession is allowed.
const DEBOUNCE_MS: u8 = 6;

const DEBOUNCE_TICKS: u8 = DEBOUNCE_MS / (SCAN_LOOP_RATE_MS as u8);

/// The linker will place this boot block at the start of our program image. We
/// need this to help the ROM bootloader get our code up and running.
#[link_section = ".boot2"]
#[used]
pub static BOOT2: [u8; 256] = rp2040_boot2::BOOT_LOADER_W25Q080;

const NUM_COLS: usize = 14;
const NUM_ROWS: usize = 6;

const EXTERNAL_CRYSTAL_FREQUENCY_HZ: u32 = 12_000_000;

/// The USB Device Driver (shared with the interrupt).
static mut USB_DEVICE: Option<UsbDevice<usb::UsbBus>> = None;

/// The USB Bus Driver (shared with the interrupt).
static mut USB_BUS: Option<UsbBusAllocator<usb::UsbBus>> = None;

/// The USB Human Interface Device Driver (shared with the interrupt).
static USB_HID_CLASS: Mutex<RefCell<Option<HidClass<usb::UsbBus>>>> =
    Mutex::new(RefCell::new(None));

static ATTEMPT_REMOTE_WAKEUP: AtomicBool = AtomicBool::new(false);

#[defmt::panic_handler]
fn panic() -> ! {
    cortex_m::asm::udf()
}

#[cortex_m_rt::entry]
fn main() -> ! {
    info!("Start of main()");
    let mut pac = pac::Peripherals::take().unwrap();
    let core = pac::CorePeripherals::take().unwrap();

    let mut watchdog = Watchdog::new(pac.WATCHDOG);

    let clocks = rp2040_hal::clocks::init_clocks_and_plls(
        EXTERNAL_CRYSTAL_FREQUENCY_HZ,
        pac.XOSC,
        pac.CLOCKS,
        pac.PLL_SYS,
        pac.PLL_USB,
        &mut pac.RESETS,
        &mut watchdog,
    )
    .ok()
    .unwrap();

    // Get the GPIO peripherals.
    let sio = rp2040_hal::Sio::new(pac.SIO);

    let pins =
        rp2040_hal::gpio::Pins::new(pac.IO_BANK0, pac.PADS_BANK0, sio.gpio_bank0, &mut pac.RESETS);

    // Set up keyboard matrix pins.
    let mut rows: [&mut dyn InputPin<Error = Infallible>; NUM_ROWS] = [
        &mut pins.gpio26.into_pull_down_input(),
        &mut pins.gpio25.into_pull_down_input(),
        &mut pins.gpio27.into_pull_down_input(),
        &mut pins.gpio28.into_pull_down_input(),
        &mut pins.gpio15.into_pull_down_input(),
        &mut pins.gpio24.into_pull_down_input(),
    ];

    let mut cols: [&mut dyn OutputPin<Error = Infallible>; NUM_COLS] = [
        &mut pins.gpio29.into_push_pull_output(),
        &mut pins.gpio16.into_push_pull_output(),
        &mut pins.gpio17.into_push_pull_output(),
        &mut pins.gpio18.into_push_pull_output(),
        &mut pins.gpio9.into_push_pull_output(),
        &mut pins.gpio10.into_push_pull_output(),
        &mut pins.gpio19.into_push_pull_output(),
        &mut pins.gpio11.into_push_pull_output(),
        &mut pins.gpio12.into_push_pull_output(),
        &mut pins.gpio13.into_push_pull_output(),
        &mut pins.gpio14.into_push_pull_output(),
        &mut pins.gpio20.into_push_pull_output(),
        &mut pins.gpio22.into_push_pull_output(),
        &mut pins.gpio23.into_push_pull_output(),
    ];

    // Initialize a delay for accurate sleeping.
    let mut delay = cortex_m::delay::Delay::new(core.SYST, clocks.system_clock.freq().to_Hz());
    let timer = rp2040_hal::Timer::new(pac.TIMER, &mut pac.RESETS, &clocks);

    let mut modifier_mask = [[false; NUM_ROWS]; NUM_COLS];
    for (col, mapping_col) in modifier_mask.iter_mut().zip(TRANSPOSED_NORMAL_LAYER_MAPPING) {
        for (key, mapping_key) in col.iter_mut().zip(mapping_col) {
            *key = mapping_key.is_modifier();
        }
    }

    // Create a global debounce state to prevent unintended rapid key double-presses.
    let mut debounce: Debounce<NUM_ROWS, NUM_COLS> = Debounce::new(DEBOUNCE_TICKS, modifier_mask);

    // Do an initial scan of the keys so that we immediately have something to report to the host when asked.
    let scan = KeyScan::scan(&mut rows, &mut cols, &mut delay, &mut debounce);

    // If the Escape key is pressed during power-on, we should go into bootloader mode.
    if scan[0][0] {
        let gpio_activity_pin_mask = 0;
        let disable_interface_mask = 0;
        info!("Escape key detected on boot, going into bootloader mode.");
        rp2040_hal::rom_data::reset_to_usb_boot(gpio_activity_pin_mask, disable_interface_mask);
    }

    info!("Initializing USB");
    // Initialize USB
    let force_vbus_detect_bit = true;
    let usb_bus = UsbBus::new(
        pac.USBCTRL_REGS,
        pac.USBCTRL_DPRAM,
        clocks.usb_clock,
        force_vbus_detect_bit,
        &mut pac.RESETS,
    );
    let bus_allocator = UsbBusAllocator::new(usb_bus);
    let bus_allocator_ref = unsafe {
        // Note (safety): This is safe as interrupts haven't been started yet
        USB_BUS = Some(bus_allocator);
        // We are promising to the compiler not to take mutable access to this global
        // variable while this reference exists!

        // TODO(bschwind) - Fix this lint: https://doc.rust-lang.org/nightly/edition-guide/rust-2024/static-mut-references.html
        #[allow(static_mut_refs)]
        USB_BUS.as_ref().unwrap()
    };

    let hid_class = HidClass::new(bus_allocator_ref);

    // https://github.com/obdev/v-usb/blob/7a28fdc685952412dad2b8842429127bc1cf9fa7/usbdrv/USB-IDs-for-free.txt#L128
    let keyboard_usb_device = UsbDeviceBuilder::new(bus_allocator_ref, UsbVidPid(0x16c0, 0x27db))
        .supports_remote_wakeup(true)
        .strings(&[StringDescriptors::default().manufacturer("bschwind").product("key ripper")])
        .unwrap()
        .build();

    unsafe {
        // Note (safety): This is safe as interrupts haven't been started yet
        critical_section::with(|cs| {
            USB_HID_CLASS.replace(cs, Some(hid_class));
        });

        USB_DEVICE = Some(keyboard_usb_device);
    }
    info!("Enabling USB interrupt handler");
    unsafe {
        pac::NVIC::unmask(pac::Interrupt::USBCTRL_IRQ);
    }
    info!("Entering main loop");

    let mut tick_count_down = timer.count_down();
    tick_count_down.start(1.millis());

    let mut last_report: KeyboardReport = scan.into();

    loop {
        if tick_count_down.wait().is_ok() {
            let scan = KeyScan::scan(&mut rows, &mut cols, &mut delay, &mut debounce);
            let report: KeyboardReport = scan.into();

            if report != last_report {
                critical_section::with(|cs| {
                    let mut hid_class = USB_HID_CLASS.borrow_ref_mut(cs);
                    let hid_class = hid_class.as_mut().unwrap();

                    if let Err(err) = hid_class.write_raw_report(&report.as_raw_input()) {
                        match err {
                            UsbError::WouldBlock => warn!("UsbError::WouldBlock"),
                            UsbError::ParseError => error!("UsbError::ParseError"),
                            UsbError::BufferOverflow => error!("UsbError::BufferOverflow"),
                            UsbError::EndpointOverflow => error!("UsbError::EndpointOverflow"),
                            UsbError::EndpointMemoryOverflow => {
                                error!("UsbError::EndpointMemoryOverflow")
                            },
                            UsbError::InvalidEndpoint => error!("UsbError::InvalidEndpoint"),
                            UsbError::Unsupported => error!("UsbError::Unsupported"),
                            UsbError::InvalidState => error!("UsbError::InvalidState"),
                        }
                    } else {
                        // Only assign to last_report if it was successfully reported.
                        last_report = report;
                    }
                });

                // If the input report has changed, we should attempt a remote wakeup
                // if the device is suspended.
                ATTEMPT_REMOTE_WAKEUP.store(true, Ordering::Relaxed);
            }
        }
    }
}

/// Handle USB interrupts
#[allow(non_snake_case)]
#[interrupt]
unsafe fn USBCTRL_IRQ() {
    // TODO(bschwind) - Fix this lint: https://doc.rust-lang.org/nightly/edition-guide/rust-2024/static-mut-references.html
    #[allow(static_mut_refs)]
    let usb_dev = USB_DEVICE.as_mut().unwrap();

    critical_section::with(|cs| {
        let mut hid_class = USB_HID_CLASS.borrow_ref_mut(cs);
        let hid_class = hid_class.as_mut().unwrap();

        usb_dev.poll(&mut [hid_class]);

        if usb_dev.state() == UsbDeviceState::Suspend
            && usb_dev.remote_wakeup_enabled()
            && ATTEMPT_REMOTE_WAKEUP.load(Ordering::Relaxed)
        {
            usb_dev.bus().remote_wakeup();
        }

        ATTEMPT_REMOTE_WAKEUP.store(false, Ordering::Relaxed);
    });
}

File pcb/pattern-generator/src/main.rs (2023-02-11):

use std::ops::{Add, Mul};

const SQUARE_SIZE: f64 = 2.5;

fn main() {
    let board_width = 285.0;
    let board_height = 130.0;

    let diagonal = (SQUARE_SIZE * SQUARE_SIZE + SQUARE_SIZE * SQUARE_SIZE).sqrt();
    let half_diagonal = diagonal / 2.0;

    let mut x = 0.0;

    while x < board_width {
        let mut y = 0.0;

        let t = x / (board_width);

        let mut counter = 0;
        while y < board_height {
            let x = if counter % 2 == 0 { x } else { x + half_diagonal };
            draw_square(x, y, t);

            y += half_diagonal;
            counter += 1;
        }

        x += diagonal;
    }
}

fn draw_square(x: f64, y: f64, t: f64) {
    let diagonal = (SQUARE_SIZE * SQUARE_SIZE + SQUARE_SIZE * SQUARE_SIZE).sqrt();
    let half_diagonal = diagonal / 2.0;

    let t = map_triangle(t);

    let y_offset = lerp(y + diagonal - 0.1, y + half_diagonal + 0.1, t);
    let points = vec![
        (x - half_diagonal, y + half_diagonal),
        (x, y + diagonal),
        (x + half_diagonal, y + half_diagonal),
        (x, y_offset),
        (x - half_diagonal, y + half_diagonal),
    ];

    println!("(polygon");
    println!("  (pts");

    for (x, y) in points {
        println!("    (xy {x} {y})");
    }

    println!("  )");
    println!(")");
}

// Maps [0.0, 0.5) to [0.0, 1.0],
// and [0.5, 1.0) to [1.0, 0.0]
fn map_triangle(t: f64) -> f64 {
    1.0 - 2.0 * (t - 0.5).abs()
}

fn lerp<T>(a: T, b: T, t: f64) -> T
where
    T: Add<Output = T> + Mul<f64, Output = T>,
{
    (a * (1.0 - t)) + (b * t)
}

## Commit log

2022-06-12 Add the keyboard matrix circuit
    [key-ripper.kicad_sch]
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2022-06-12 Add USB connector and voltage regulator
    [key-ripper.kicad_sch]
2022-06-12 Add RP2040 and connect basic power pins
    [key-ripper.kicad_sch]
2022-06-12 Add power LED, tidy up schematic sections
    [key-ripper.kicad_sch]
2022-06-12 Add crystal oscillator, reset circuit, serial-wire debug circuits
    [key-ripper.kicad_sch]
2022-06-12 Add the QSPI flash memory
    [key-ripper.kicad_sch]
2022-06-12 Assign row/column connections to GPIO pins
    [key-ripper.kicad_sch]
2022-06-12 Typo fix
    [key-ripper.kicad_sch]
2022-06-13 Add a pullup resistor the the RUN pin
    [key-ripper.kicad_sch]
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2022-06-17 Start the PCB layout
    [key-ripper.kicad_pcb, key-ripper.kicad_sch]
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2022-06-17 Add potential location for RP2040
    [key-ripper.kicad_pcb]
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2022-06-17 Use tactile switch for the reset and boot buttons
    [key-ripper.kicad_sch]
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2022-06-18 Relabel switches to be contiguous
    [key-ripper.kicad_pcb, key-ripper.kicad_sch]
2022-06-18 Start placing RP2040 components
    [key-ripper.kicad_pcb]
2022-06-18 Place all decoupling capacitors for the rp2040
    [key-ripper.kicad_pcb, key-ripper.kicad_sch]
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2022-06-18 Add a copper ground pour
    [key-ripper.kicad_pcb]
2022-06-18 Route the 3v3 traces
    [key-ripper.kicad_pcb]
2022-06-18 Relocate crystal and some 3v3 traces
    [key-ripper.kicad_pcb]
2022-06-19 Some sort of crappy QSPI routing...
    [key-ripper.kicad_pcb]
2022-06-29 Re-do layout, group components together
    [key-ripper.kicad_pcb]
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2022-06-29 More groupings and layout
    [key-ripper.kicad_pcb]
2022-06-29 Rearrange keys in the matrix for better routing
    [key-ripper.kicad_sch]
2022-06-29 Update PCB with new matrix layout
    [key-ripper.kicad_pcb]
2022-06-29 Organize key matrix vias
    [key-ripper.kicad_pcb]
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2022-06-29 Move Fn row down to be flush with number row
    [key-ripper.kicad_pcb]
2022-06-29 Reattach USB C differential pair
    [key-ripper.kicad_pcb]
2022-06-29 Make the edge cutouts even smaller
    [key-ripper.kicad_pcb]
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2022-06-29 Move QSPI flash closer to the RP2040
    [key-ripper.kicad_pcb]
2022-06-29 Tune the skew of the USB differential pair
    [key-ripper.kicad_pcb]
2022-06-29 Undo skew tuning, probably not needed for now
    [key-ripper.kicad_pcb]
2022-06-29 Everything is ready to be routed
    [key-ripper.kicad_pcb]
2022-06-29 Start routing power, simplify SWD connector
    [key-ripper.kicad_pcb, key-ripper.kicad_sch]
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2022-06-29 Move row vias up a bit
    [key-ripper.kicad_pcb]
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2022-06-29 Connect the key switches to their respective diodes
    [key-ripper.kicad_pcb]
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2022-06-29 Connect switch rows together, clean up stray traces
    [key-ripper.kicad_pcb]
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2022-06-29 Fix silkscreens
    [key-ripper.kicad_pcb, key-ripper.kicad_sch]
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2022-06-29 Add pin 1 markers and diode polarity markers
    [key-ripper.kicad_pcb]
2022-06-29 Fix the SWD silkscreen
    [key-ripper.kicad_pcb]
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2022-06-29 Update parts list, add start of BOM list
    [bom.csv]
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2022-06-29 Move entire file down to be in positive coordinates
    [key-ripper.kicad_pcb]
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2022-07-06 Fix row and column sizes
    [main.rs]
2022-07-07 Fix matrix mapping formatting, add missing keyboard row
    [main.rs]
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2022-07-09 Working HID Descriptor (#10)
    * Add a working keyboard HID descriptor
    * Fix a comment, code formatting
    * Make the formatting more compact
    [main.rs]
2022-07-10 Fix the placement of the F5 key
    [key-ripper.kicad_pcb]
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2022-07-10 Use the soldered MX footprint instead of kailh hotswap footprint
    [key-ripper.kicad_sch]
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2022-08-17 Top plate v0.1 (#19)
    * Add a top plate project file
    * Update top plate footprints
    * Update the footprints for the top plate
    * Add production files for the top plate
    [top-plate-B_Cu.gbl, top-plate-B_Mask.gbs, top-plate-B_Paste.gbp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]
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2022-08-17 Move the top plate F5 key to the proper spot
    [top-plate.kicad_pcb]
2022-08-17 Adjust the silkscreen to be on the front side, mark it v0.2
    [top-plate.kicad_pcb]
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2022-11-10 Fix USB C connector footprint
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2022-12-04 Add threaded PCB insertsj, clean up switch matrix wiring
    [key-ripper.kicad_sch]
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2022-12-30 Add M2 spacer pass-through mounting holes to the schematic
    [key-ripper.kicad_sch]
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2022-12-30 Add footprints for the hex spacer pass-through edge cuts
    [key-ripper.kicad_sch]
2022-12-30 Fix a lot of silkscreen issues
2022-12-31 More silkscreen fixups
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2023-01-02 Change the crystal capacitor footprints to 1608 metric size
    [key-ripper.kicad_sch]
2023-01-02 Add LCSC part numbers to the schematic symbols
    [key-ripper.kicad_sch]
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2023-01-05 Use a TRRS connector for the SWD debug port
    [key-ripper.kicad_sch]
2023-01-05 Add a test point for providing a 5V debug power supply (if you want to avoid USB bus power)
    [key-ripper.kicad_sch]
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2023-01-06 Move the crystal oscillator a bit away from the stabilizer hole
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2023-01-28 Re-align top plate to the same grid as the PCB
    [top-plate.kicad_pcb]
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2023-01-29 Add the remaining M2 holes for the top plate
    [top-plate.kicad_pcb]
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2023-01-31 Fix top-plate gerber path in kitspace.yaml (#46)
2023-02-08 Use the copper pour on the bottom plate on both sides
    [bottom-plate.kicad_pcb]
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2023-02-08 Small track and silkscreen fixups
2023-02-08 Add some patterns to the top and bottom plate copper pours
    [top-plate.kicad_pcb]
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2023-02-10 Pattern generator (#48)
    * Initial pattern generator commit
    * Cleanup unused code and format
    * Add a triangle-gradient copper pour pattern to the bottom plate
    * Fix a gap in the copper pour
    [main.rs]
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2023-04-23 Change top plate cutouts to pcb-mounted stabilizer style
    [top-plate.kicad_pcb]
2023-04-23 Add production files for the pcb-mount stabilizer top plate
    [top-plate-B_Mask.gbs, top-plate-B_Paste.gbp, top-plate-B_Silkscreen.gbo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]
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2024-06-22 Fix the 'report_is_empty()' function (#57)
    [main.rs]
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2024-07-12 Don't send duplicate reports (#61)
    * Don't send duplicate reports
    * Revert dependency change
    [main.rs]
2024-07-12 NIH HID (#63)
    * Start adding our own HID class implementation
    * Basic version of the HID class works
    * Tweak the doc comments a bit
    * Add some comments
    * Remove the usbd-hid crate
    * Reduce the matrix scan time from roughly 280µs to 14µs
    * Fix a bug with repeating keys
    [key_scan.rs, main.rs]
2024-07-21 Update to kicad 8.0 (#65)
    * Update project, schematic, and pcb to kicad 8.0
    * Update part libraries
    * Update the parts lib again for kicad 8.0
    [key-ripper.kicad_sch]
2024-07-21 ESD Protection (#66)
    * Add an ESD protection diode to the USB lines
    * Add ESD protection on the PCB
    [key-ripper.kicad_sch]
2024-07-23 Use USBLC6-2SC6 for ESD protection on the USB line
    [key-ripper.kicad_sch]
2024-07-25 Indicate the correct LED color
    [key-ripper.kicad_sch]
2025-07-03 Add case STEP files (#68)
    * Add case STEP files
    * Update the README with links to the case
    [case_feet.step, keyboard.step]
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
